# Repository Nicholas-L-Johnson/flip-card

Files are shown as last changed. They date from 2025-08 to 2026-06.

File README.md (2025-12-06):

This repo contains all files related to the flip-card project, which is a business card that runs a fluid-implicit-particle(FLIP) simulation.



The PCB design files are in the "kicad-pcb" folder. The flip-card project is inspired by mitxela's fluid simulation pendant project https://mitxela.com/projects/fluid-pendant

The fluid simulation logic is contained in a standalone crate, which is in the "fluid_sim_crate" folder. This is based off the work by Matthias Müller (https://github.com/matthias-research) and his excelent demonstrations on his youtube channel "Ten Minute Physics"

One of the more difficult features was the rechargable battery.  I found a design for a board edge usb-c port from cnlohr's tiny touch lcd project https://github.com/cnlohr/ch32v003_3digit_lcd_usb/



a WASM simulator is also provided in the "sim_display" folder, which is what I use to debug issues in the simulation.

The implementation for the fluid simulation on the rp2350 is in the "flip-card_firmware" file

further details can be found in each folder's README files, **see flashing instructions in the flip-card_firmware subfolder**



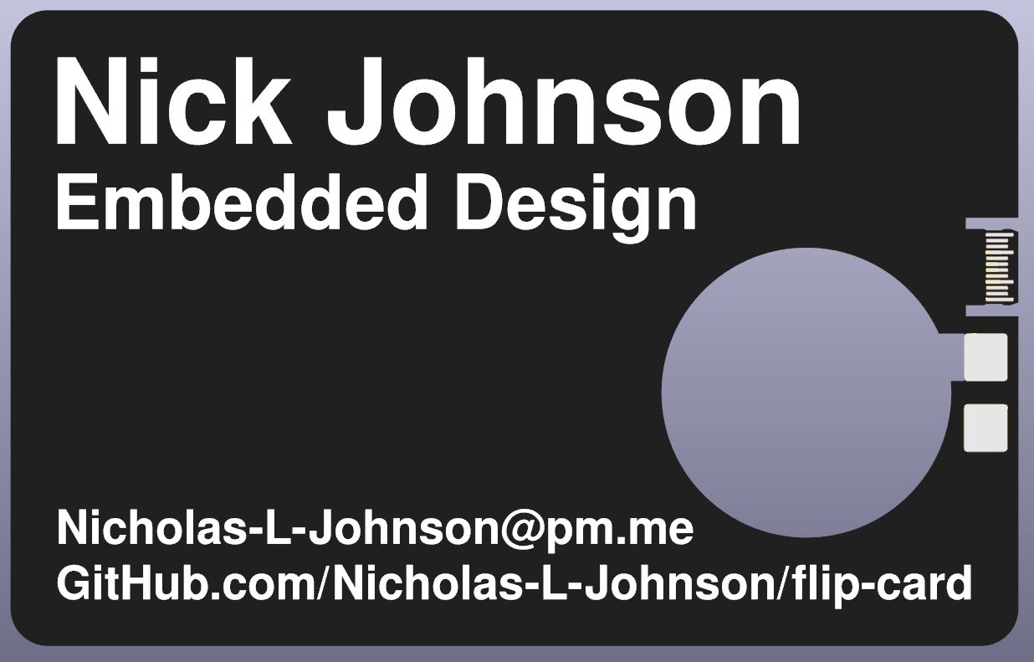
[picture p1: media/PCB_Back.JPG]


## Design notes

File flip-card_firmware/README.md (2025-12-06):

## Firmware
This is where all the logic lies for running the screen and reading the accelerometer.

Everything here centers around the Embassy framework.  Embassy is by far the easiest way to get into embedded rust.

Most of the complexity here stems from the need to drive a charlieplexed LED array.  The PIO peripheral is a godsend for this, it lets the data stream directly into GPIO signals without any use of the main 2 cores.

Speaking of performance, the simulation uses both cores running at 150 MHz.  The board runs at 40mA, and most of that is the controller, not the LEDs.  The lowest power mode available for the rust pac is the DORMANT state, which only brings the power usage down to 1.5mA.

That's really the only TODO here.  The RP2350 has some wonderful support for power domains, but the rust crates just don't support them yet.  Right now the card only lasts about 2-3 days in sleep mode before it needs charged again.

## Build and Install

Installing the firmware onto the card is pretty straightforward, just clone the whole repo into a folder and cd into the firmware folder.  There are two pre-requisites that must be met before flashing:

1) Because the card uses the Raspberry Pi Pico 2 (RP2350) you must have Picotool installed in order to load firmware.  You can find Picotool here: https://github.com/raspberrypi/picotool
2) The card must be connected via a usb-c cord (into the cutout on the board) and mount a volume when connected to your computer (it should do this by default for new cards, but read below for re-programming cards)

Once those pre-requisites are satisfied, you can install the firmware by simply running:
```
cargo run --release
```
(don't forget the --release or it will not work, and will need to be forced back to bootloader mode via the method below)

That will compile the binary, and then use picotool to load the binary onto the RP2350.

## Re-Programming an already programmed card

The card can be returned to bootloader mode (where it appears as a volume on a connected PC and can be re-flashed) in two ways.  

First, with the board powered, you can short the "GND" contact to the "BOOT" contact, then with that short in place, breifly short the "GND" contact to the "RUN" contact.  Then remove all the shorts and it should be in bootloader mode.

Second, the latest version of the code has a backup method. the card can be placed perfectly upside down (so all the fluid goes to the top of the screen) for 5 seconds, and that will kick it back to bootloader mode.  Note that the board will be stuck in that mode until the program is re-flashed, or the rp2350 loses all power.

## OPTIONAL

If you want to disable the backup method to go back to bootloader (becuse you don't want the card to ever accidentally go to bootloader mode) in main.rs, uncomment line 794 (the udf() function) and comment out line 793(the reboot() function), THEN run the build and install steps above.

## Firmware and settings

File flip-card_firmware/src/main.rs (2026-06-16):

#![no_std]
#![no_main]

use core::cell::RefCell;
use core::default;

use cortex_m::interrupt::{self, Mutex};
use embassy_executor::{Executor, Spawner};
use embassy_futures::select::{Either::First, select};
use embassy_rp::bind_interrupts;
use embassy_rp::gpio;
use embassy_rp::gpio::DormantWakeConfig;
use embassy_rp::gpio::Input;
use embassy_rp::gpio::Pull;
use heapless::Vec;
// use embassy_rp::gpio::{Input, Pull};
use embassy_rp::clocks::{ClockConfig, CoreVoltage, clk_sys_freq, core_voltage};
use embassy_rp::i2c;
use embassy_rp::i2c::I2c;
use embassy_rp::i2c::InterruptHandler as I2C_InterruptHandler;
use embassy_rp::multicore::{Stack, spawn_core1};
use embassy_rp::peripherals::*;
use embassy_rp::pio::program::pio_asm;
use embassy_rp::pio::{Config, InterruptHandler, Pio, ShiftConfig, ShiftDirection};
use embassy_rp::watchdog::*;
use embassy_sync::blocking_mutex::raw::CriticalSectionRawMutex;
use embassy_time::Duration;
use embassy_time::Timer;
use fixed::traits::ToFixed;
use fixed_macro::types::U56F8;
use fluid_sim::FluidSimulation::Scene;
use gpio::{Level, Output};

use static_cell::StaticCell;
// use {defmt_rtt as _, panic_probe as _};

static mut CORE1_STACK: Stack<262144> = Stack::new();
static EXECUTOR0: StaticCell<Executor> = StaticCell::new();
static EXECUTOR1: StaticCell<Executor> = StaticCell::new();
// static CHANNEL: Channel<CriticalSectionRawMutex, LedState, 1> = Channel::new();

static BIT21: u32 = 0b00000000001000000000000000000000; // pinout 19 1
static BIT20: u32 = 0b00000000000100000000000000000000; // pinout 19 2
static BIT19: u32 = 0b00000000000010000000000000000000; // pinout 19 3
static BIT18: u32 = 0b00000000000001000000000000000000; // pinout 18 4
static BIT17: u32 = 0b00000000000000100000000000000000; // pinout 17 5
static BIT16: u32 = 0b00000000000000010000000000000000; // pinout 16 6
static BIT15: u32 = 0b00000000000000001000000000000000; // pinout 15 7
static BIT14: u32 = 0b00000000000000000100000000000000; // pinout 14 8
static BIT13: u32 = 0b00000000000000000010000000000000; // pinout 13 9
static BIT12: u32 = 0b00000000000000000001000000000000; // pinout 12 10
static BIT11: u32 = 0b00000000000000000000100000000000; // pinout 11 11
static BIT10: u32 = 0b00000000000000000000010000000000; // pinout 10 12
static BIT9: u32 = 0b00000000000000000000001000000000; // pinout 9 13
static BIT8: u32 = 0b00000000000000000000000100000000; // pinout 8 14
static BIT7: u32 = 0b00000000000000000000000010000000; // pinout 7 15
static BIT6: u32 = 0b00000000000000000000000001000000; // pinout 6 16
static BIT5: u32 = 0b00000000000000000000000000100000; // pinout 5 17
static BIT4: u32 = 0b00000000000000000000000000010000; // pinout 4 18
static BIT3: u32 = 0b00000000000000000000000000001000; // pinout 3 19
static BIT2: u32 = 0b00000000000000000000000000000100; // pinout 2 20
static BIT1: u32 = 0b00000000000000000000000000000010; // pinout 1 21
static BIT0: u32 = 0b00000000000000000000000000000001; // pinout 1 21

static FRAME_DATA_SIGNAL: embassy_sync::signal::Signal<CriticalSectionRawMutex, [[bool; 21]; 21]> =
    embassy_sync::signal::Signal::new();

static ACCEL_DATA_SIGNAL: embassy_sync::signal::Signal<CriticalSectionRawMutex, [f32; 2]> =
    embassy_sync::signal::Signal::new();

static BITS: [u32; 22] = [
    BIT21, BIT20, BIT19, BIT18, BIT17, BIT16, BIT15, BIT14, BIT13, BIT12, BIT11, BIT10, BIT9, BIT8,
    BIT7, BIT6, BIT5, BIT4, BIT3, BIT2, BIT1, BIT0,
];
static WATCHDOG: Mutex<RefCell<Option<Watchdog>>> = Mutex::new(RefCell::new(None));

static LOOKUP_TABLE: [[usize; 21]; 21] = [
    [
        416, 481, 373, 435, 327, 389, 281, 343, 235, 297, 189, 251, 143, 205, 097, 159, 051, 113,
        005, 067, 025,
    ],
    [
        459, 372, 479, 329, 433, 283, 387, 237, 341, 191, 295, 145, 249, 099, 203, 053, 157, 007,
        111, 027, 068,
    ],
    [
        370, 457, 328, 477, 285, 431, 239, 385, 193, 339, 147, 293, 101, 247, 055, 201, 009, 155,
        029, 112, 071,
    ],
    [
        413, 326, 455, 284, 475, 241, 429, 195, 383, 149, 337, 103, 291, 057, 245, 011, 199, 031,
        156, 073, 114,
    ],
    [
        324, 411, 282, 453, 240, 473, 197, 427, 151, 381, 105, 335, 059, 289, 013, 243, 033, 200,
        075, 158, 117,
    ],
    [
        367, 280, 409, 238, 451, 196, 471, 153, 425, 107, 379, 061, 333, 015, 287, 035, 244, 077,
        202, 119, 160,
    ],
    [
        278, 365, 236, 407, 194, 449, 152, 469, 109, 423, 063, 377, 017, 331, 037, 288, 079, 246,
        121, 204, 163,
    ],
    [
        321, 234, 363, 192, 405, 150, 447, 108, 467, 065, 421, 019, 375, 039, 332, 081, 290, 123,
        248, 165, 206,
    ],
    [
        232, 319, 190, 361, 148, 403, 106, 445, 064, 465, 021, 419, 041, 376, 083, 334, 125, 292,
        167, 250, 209,
    ],
    [
        275, 188, 317, 146, 359, 104, 401, 062, 443, 020, 463, 043, 420, 085, 378, 127, 336, 169,
        294, 211, 252,
    ],
    [
        186, 273, 144, 315, 102, 357, 060, 399, 018, 441, 042, 464, 087, 422, 129, 380, 171, 338,
        213, 296, 255,
    ],
    [
        229, 142, 271, 100, 313, 058, 355, 016, 397, 040, 442, 086, 466, 131, 424, 173, 382, 215,
        340, 257, 298,
    ],
    [
        140, 227, 098, 269, 056, 311, 014, 353, 038, 398, 084, 444, 130, 468, 175, 426, 217, 384,
        259, 342, 301,
    ],
    [
        183, 096, 225, 054, 267, 012, 309, 036, 354, 082, 400, 128, 446, 174, 470, 219, 428, 261,
        386, 303, 344,
    ],
    [
        094, 181, 052, 223, 010, 265, 034, 310, 080, 356, 126, 402, 172, 448, 218, 472, 263, 430,
        305, 388, 347,
    ],
    [
        137, 050, 179, 008, 221, 032, 266, 078, 312, 124, 358, 170, 404, 216, 450, 262, 474, 307,
        432, 349, 390,
    ],
    [
        048, 135, 006, 177, 030, 222, 076, 268, 122, 314, 168, 360, 214, 406, 260, 452, 306, 476,
        351, 434, 393,
    ],
    [
        091, 004, 133, 028, 178, 074, 224, 120, 270, 166, 316, 212, 362, 258, 408, 304, 454, 350,
        478, 395, 436,
    ],
    [
        002, 089, 026, 134, 072, 180, 118, 226, 164, 272, 210, 318, 256, 364, 302, 410, 348, 456,
        394, 480, 439,
    ],
    [
        045, 024, 090, 070, 136, 116, 182, 162, 228, 208, 274, 254, 320, 300, 366, 346, 412, 392,
        458, 438, 482,
    ],
    [
        023, 046, 069, 092, 115, 138, 161, 184, 207, 230, 253, 276, 299, 322, 345, 368, 391, 414,
        437, 460, 461,
    ],
];

struct Screen {
    yx_grid: [[bool; 21]; 21],
    yx_lock_grid: [[bool; 21]; 21],
    index_grid: [bool; 484],
    out_array: [u32; 506],
    out_array_2: Vec<u32, 1452>,
}
impl Screen {
    fn fill_index(&mut self) {
        self.index_grid = [false; 484];
        for y in 0..21 {
            for x in 0..21 {
                if self.yx_grid[y][x] {
                    self.index_grid[LOOKUP_TABLE[y][x]] = true
                }
            }
        }
    }
    fn post_process(&mut self) {
        // Temporary grid to track which liquid cells will become stable/locked this frame
        let mut temp_yx_lock_grid = [[false; 21]; 21];

        // PHASE 1: Liquid Stabilization Detection
        // Find liquid cells that are completely contained (surrounded by liquid or boundaries)
        // These cells will become "stable" and won't flow away in future iterations
        for i in 0..21 {
            for j in 0..21 {
                if self.yx_grid[i][j] {
                    // Only process existing liquid cells
                    // Check if liquid is completely contained (can't flow in any direction)
                    // A cell is contained if all 4 neighbors are either liquid or boundaries
                    temp_yx_lock_grid[i][j] = (i == 20 || self.yx_grid[i + 1][j]) &&  // Bottom: boundary or liquid
                        (i == 0  || self.yx_grid[i - 1][j]) &&  // Top: boundary or liquid
                        (j == 20 || self.yx_grid[i][j + 1]) &&  // Right: boundary or liquid
                        (j == 0  || self.yx_grid[i][j - 1]); // Left: boundary or liquid
                }
            }
        }

        // PHASE 2: Stable Liquid Reinforcement
        // For liquid that was stable in the previous frame, check if it should remain liquid
        // This prevents stable liquid from disappearing due to flow dynamics
        for i in 0..21 {
            for j in 0..21 {
                if self.yx_lock_grid[i][j] {
                    // Process previously stable liquid
                    // Re-check if this stable liquid is still contained
                    let is_surrounded = (i == 20 || self.yx_grid[i + 1][j])
                        && (i == 0 || self.yx_grid[i - 1][j])
                        && (j == 20 || self.yx_grid[i][j + 1])
                        && (j == 0 || self.yx_grid[i][j - 1]);

                    if is_surrounded {
                        // Reinforce: ensure this cell remains liquid (prevent evaporation/flow)
                        self.yx_grid[i][j] = true;
                    }
                    // If not surrounded anymore, let natural flow dynamics handle it
                    // (don't force it to empty - preserve liquid conservation)
                }
            }
        }

        // Update stability tracking for next iteration
        // Replace old stable cell tracking with newly calculated stable cells
        self.yx_lock_grid = temp_yx_lock_grid;
    }
    fn make_output(&mut self) {
        self.out_array = [0; 506];
        let mut index = 0;
        let mut counter = 0;

        for i in 0..BITS.len() {
            self.out_array[counter] = BITS[i];
            index += 1;
            counter += 1;
            for j in 0..BITS.len() {
                if i != j {
                    if self.index_grid[index] {
                        self.out_array[counter] = BITS[i] | BITS[j];
                    }
                    index += 1;
                    counter += 1;
                }
            }
            // counter += 1;
        }
    }
    fn make_output_2(&mut self) {
        self.out_array_2 = Vec::new();
        let mut index = 0;
        for i in 0..BITS.len() {
            index += 1;
            for j in 0..BITS.len() {
                if i != j {
                    if self.index_grid[index] {
                        self.out_array_2.push(BITS[i]).unwrap();
                        self.out_array_2.push(BITS[i] | BITS[j]).unwrap();
                        self.out_array_2.push(0).unwrap();
                    }
                    index += 1;
                }
            }
        }
        if self.index_grid[461] {
            self.out_array_2.push(BITS[21]).unwrap();
            self.out_array_2.push(BITS[21] | BITS[20]).unwrap();
            self.out_array_2.push(0).unwrap();
        }
    }
    fn _disp_num(&mut self, num: usize, yloc: usize, xloc: usize) {
        let ymin = yloc;
        let ymax = yloc + 7;
        let xmin = xloc;
        let xmax = xloc + 5;

        for y in ymin..ymax {
            for x in xmin..xmax {
                self.yx_grid[y][x] = false;
            }
        }
        match num {
            0 => {
                self.yx_grid[ymin + 1][xmin + 1] = true;
                self.yx_grid[ymin + 2][xmin + 1] = true;
                self.yx_grid[ymin + 3][xmin + 1] = true;
                self.yx_grid[ymin + 4][xmin + 1] = true;
                self.yx_grid[ymin + 5][xmin + 1] = true;

                self.yx_grid[ymin + 1][xmin + 2] = true;
                //self.yx_grid[ymin +3][xmin + 2] = true;
                self.yx_grid[ymin + 5][xmin + 2] = true;

                self.yx_grid[ymin + 1][xmin + 3] = true;
                self.yx_grid[ymin + 2][xmin + 3] = true;
                self.yx_grid[ymin + 3][xmin + 3] = true;
                self.yx_grid[ymin + 4][xmin + 3] = true;
                self.yx_grid[ymin + 5][xmin + 3] = true;
            }
            1 => {
                // self.yx_grid[ymin + 1][xmin + 1] = true;
                // self.yx_grid[ymin + 2][xmin + 1] = true;
                // self.yx_grid[ymin + 3][xmin + 1] = true;
                // self.yx_grid[ymin + 4][xmin + 1] = true;
                // self.yx_grid[ymin + 5][xmin + 1] = true;

                // self.yx_grid[ymin + 1][xmin + 2] = true;
                // self.yx_grid[ymin +3][xmin + 2] = true;
                // self.yx_grid[ymin + 5][xmin + 2] = true;

                self.yx_grid[ymin + 1][xmin + 3] = true;
                self.yx_grid[ymin + 2][xmin + 3] = true;
                self.yx_grid[ymin + 3][xmin + 3] = true;
                self.yx_grid[ymin + 4][xmin + 3] = true;
                self.yx_grid[ymin + 5][xmin + 3] = true;
            }
            2 => {
                self.yx_grid[ymin + 1][xmin + 1] = true;
                // self.yx_grid[ymin + 2][xmin + 1] = true;
                self.yx_grid[ymin + 3][xmin + 1] = true;
                self.yx_grid[ymin + 4][xmin + 1] = true;
                self.yx_grid[ymin + 5][xmin + 1] = true;

                self.yx_grid[ymin + 1][xmin + 2] = true;
                self.yx_grid[ymin + 3][xmin + 2] = true;
                self.yx_grid[ymin + 5][xmin + 2] = true;
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
async fn main(_spawner: Spawner) {
    // define all the peripherals and pins
    // let mut config =
        // embassy_rp::config::Config::new(ClockConfig::system_freq(200_000_000).unwrap());
    // config.clocks.core_voltage = CoreVoltage::V1_15;
    let p = embassy_rp::init(Default::default());
    let mut i2c: I2c<'static, I2C1, i2c::Async> =
        embassy_rp::i2c::I2c::new_async(p.I2C1, p.PIN_23, p.PIN_22, Irqs, Default::default());
    interrupt::free(|cs| WATCHDOG.borrow(cs).replace(Some(Watchdog::new(p.WATCHDOG))));
    let mut enable_accel = Output::new(p.PIN_29, Level::Low);
    let pio: embassy_rp::Peri<'static, PIO0> = p.PIO0; //this PIO object is one of the 4 PIO peripherals
    let dma_out_ref: embassy_rp::Peri<'static, DMA_CH0> = p.DMA_CH0;
    let mut accel_interrupt_1 = Input::new(p.PIN_24, Pull::Up);
    let mut accel_interrupt_2 = Input::new(p.PIN_25, Pull::Up);
    // Timer::after_millis(10).await;

    // start up the peripherals
    let sm = setup_pio_2(
        pio, p.PIN_0, p.PIN_1, p.PIN_2, p.PIN_3, p.PIN_4, p.PIN_5, p.PIN_6, p.PIN_7, p.PIN_8,
        p.PIN_9, p.PIN_10, p.PIN_11, p.PIN_12, p.PIN_13, p.PIN_14, p.PIN_15, p.PIN_16, p.PIN_17,
        p.PIN_18, p.PIN_19, p.PIN_20, p.PIN_21,
    );
    enable_accel.set_high();
    let screen = Screen {
        yx_grid: [[false; 21]; 21],
        yx_lock_grid: [[false; 21]; 21],
        index_grid: [false; 484],
        out_array: [0; 506],
        out_array_2: Vec::new(),
    };

    // spawn background tasks

    spawn_core1(
        p.CORE1,
        unsafe { &mut *core::ptr::addr_of_mut!(CORE1_STACK) },
        move || {
            let executor1 = EXECUTOR1.init(Executor::new());
            executor1.run(|spawner| spawner.spawn(simulation_update()).unwrap())
        },
    );

    let executor0 = EXECUTOR0.init(Executor::new());
    executor0.run(|spawner| {
        spawner
            .spawn(monitor_accelerometer(
                i2c,
                accel_interrupt_1,
                accel_interrupt_2,
                enable_accel,
            ))
            .unwrap();
        spawner
            .spawn(drive_screen(screen, sm, dma_out_ref))
            .unwrap()
    });
}

#[embassy_executor::task(pool_size = 1)]
async fn drive_screen(
    mut screen: Screen,
    mut sm: embassy_rp::pio::StateMachine<'static, PIO0, 0>,
    mut dma_out_ref: embassy_rp::Peri<'static, DMA_CH0>,
) {
    let tx = sm.tx();
    let mut frame_count: u128 = 0;
    FRAME_DATA_SIGNAL.wait().await;
    loop {
        Timer::after_millis(1).await;
        interrupt::free(|cs| {
            if let Ok(mut watchdog) = WATCHDOG.borrow(cs).try_borrow_mut() {
                watchdog.as_mut().map(|w| w.feed());
            };
        });
        if FRAME_DATA_SIGNAL.signaled() {
            screen.yx_grid = FRAME_DATA_SIGNAL.wait().await;
            frame_count = 0;
            if screen.yx_grid == [[false; 21]; 21] {
                Timer::after_millis(3000).await;
            }
        } else {
            frame_count += 1;
        }
        screen.post_process();
        screen.fill_index();
        // screen.make_output();
        screen.make_output_2();
        tx.dma_push(dma_out_ref.reborrow(), &screen.out_array_2, false)
            .await;
        if frame_count >= 30 {
            // flash.blocking_write(reset_count_location, &[10u8]);
            // embassy_rp::rom_data::reboot(0x0002, 1, 0x00, 0x01); // reboot to BOOTSEL
            Timer::after_millis(3000).await;
        }
    }
}

#[embassy_executor::task(pool_size = 1)]
async fn monitor_accelerometer(
    mut i2c: I2c<'static, I2C1, i2c::Async>,
    mut int1: Input<'static>,
    mut int2: Input<'static>,
    mut enable_accel: Output<'static>,
) {
    //setup accelerometer
    let addr: u8 = 0x18;
    let dt: f32 = 1.0 / 100.0; // 1/Hz,
    let accel_scale_max: f32 = 9.81 * 8.0; // m/s²
    let mut xh: [u8; 1] = [0];
    i2c.blocking_write(addr, &[0x24, 0x08]).unwrap(); // CTRL_REG5, reboot chip
    i2c.blocking_write(addr, &[0x24, 0x80]).unwrap(); // CTRL_REG1, turn on, enable xyz
    Timer::after_millis(100).await;
    i2c.blocking_write(addr, &[0x20, 0x77]).unwrap(); // CTRL_REG1, turn on, enable xyz
    i2c.blocking_write(addr, &[0x21, 0x00]).unwrap(); // CTRL_REG2, high pass filter off
    i2c.blocking_write(addr, &[0x22, 0x80]).unwrap(); // CTRL_REG3, click to INT1 pin
    i2c.blocking_write(addr, &[0x23, 0x20]).unwrap(); // CTRL_REG4, FS = 8G
    // i2c.blocking_write(addr, &[0x24, 0x08]).unwrap(); // CTRL_REG5, latch INT pin 1
    i2c.blocking_write(addr, &[0x32, 0x0A]).unwrap(); // INT1_THS, Threshold = 250 mg
    i2c.blocking_write(addr, &[0x33, 0x7F]).unwrap(); // INT1_DURATION, Duration = 0
    i2c.blocking_write(addr, &[0x38, 0x22]).unwrap(); // CLICK_CFG
    i2c.blocking_write(addr, &[0x39, 0x27]).unwrap(); // CLICK_SRC
    i2c.blocking_write(addr, &[0x3A, 0x40]).unwrap(); // CLICK_THS
    i2c.blocking_write(addr, &[0x3B, 0x20]).unwrap(); // TIME_LIMIT
    i2c.blocking_write(addr, &[0x3C, 0x2F]).unwrap(); // TIME_LATENCY
    i2c.blocking_write(addr, &[0x3D, 0x30]).unwrap(); // TIME WINDOW
    // i2c.blocking_write(addr, &[0x30, 0x02]).unwrap(); // INT1_CFG, enable xh and yh interrupts
    // int1.wait_for_high().await;
    enable_accel.set_low();
    let dormant_config = DormantWakeConfig {
        edge_high: false,
        edge_low: false,
        level_high: true,
        level_low: false,
    };
    let wake = int1.dormant_wake(dormant_config.clone());
    let wake2 = int2.dormant_wake(dormant_config.clone());
    embassy_rp::clocks::dormant_sleep();
    interrupt::free(|cs| {
        if let Ok(mut watchdog) = WATCHDOG.borrow(cs).try_borrow_mut() {
            watchdog
                .as_mut()
                .map(|w| w.start(Duration::from_millis(500)));
            //.start(Duration::from_millis(500));
        };
    });
    drop(wake);
    drop(wake2);

    enable_accel.set_high();
    // i2c.blocking_write(addr, &[0x24, 0x80]).unwrap(); // CTRL_REG5, reboot chip
    i2c.blocking_write(addr, &[0x20, 0x57]).unwrap(); // CTRL_REG1, turn on, enable xy
    i2c.blocking_write(addr, &[0x23, 0x20]).unwrap(); // CTRL_REG1, turn on, enable xy
    //read accelerometer
    let mut yh: [u8; 1] = [0];
    let mut x_val: i8;
    let mut y_val: i8;
    let mut normalized_x_accel: f32;
    let mut normalized_y_accel: f32;
    let mut y_counter: usize = 0;
    let mut frame_count = 0;
    loop {
        Timer::after_millis(5).await;
        // if frame_count > 14 {
        //     embassy_rp::rom_data::reboot(0x0002, 1, 0x00, 0x01); // reboot to BOOTSEL
        // } else {
        //     frame_count += 1;
        // }
        i2c.write_read_async(addr, [0x29], &mut xh).await.unwrap(); // read accel data
        i2c.write_read_async(addr, [0x2B], &mut yh).await.unwrap(); // read accel data
        x_val = xh[0] as i8;
        y_val = yh[0] as i8;
        normalized_x_accel = (15.0 * accel_scale_max * (x_val as f32) / 128.0);
        normalized_y_accel = (15.0 * accel_scale_max * (y_val as f32) / 128.0);

        if y_val > 10 {
            y_counter += 1;
            if y_counter > 1000 {
                //embassy_rp::rom_data::reboot(0x0002, 1, 0x00, 0x01); // reboot to BOOTSEL
                cortex_m::asm::udf();
            }
        } else {
            if y_counter > 0 {
                y_counter -= 1;
            }
        }

        ACCEL_DATA_SIGNAL.signal([normalized_x_accel, -normalized_y_accel]);
    }
}

#[embassy_executor::task]
async fn simulation_update() {
    let mut scene = Scene::setupScene(250);
    ACCEL_DATA_SIGNAL.wait().await;
    let mut frame_count = 0;
    let mut miss_count = 0;
    let mut shake_count = 0;
    loop {
        if let First(accel_measurment) =
            select(ACCEL_DATA_SIGNAL.wait(), Timer::after_millis(10)).await
        {
            miss_count = 0;
            scene.set_gravity(accel_measurment);
            if accel_measurment[1] > 211.0 || accel_measurment[1] < -211.0 {
                shake_count += 100;
                if shake_count > 400 {
                    scene.particle_add(250, 250);
                }
            } else if shake_count > 0 {
                shake_count -= 1;
            }
        } else {
            miss_count += 1
        }
        if frame_count > 1000 {
            if frame_count % 60 == 0 {
                scene.particle_add(-1, 250);
            }
        }

        if !scene.is_paused() && scene.get_num_particles() > 0 && miss_count < 10 {
            frame_count += 1;
            scene.simulate();
            FRAME_DATA_SIGNAL.signal(scene.get_output());
        } else {
            if miss_count > 9 {
                cortex_m::asm::udf();
            }
            // ACCEL_DATA_SIGNAL.wait().await;
        }
    }
}
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

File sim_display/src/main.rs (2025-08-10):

use std::cell::RefCell;
use std::f32::consts::PI;
use std::rc::Rc;


use fluid_sim::FluidSimulation::*;
use wasm_bindgen::JsCast;
use wasm_bindgen::prelude::*;
use web_sys::{KeyboardEvent,HtmlCanvasElement, WebGlRenderingContext as GL, WebGlRenderingContext, window};
use yew::{Component, Context, Html, NodeRef, html};



// Wrap gl in Rc (Arc for multi-threaded) so it can be injected into the render-loop closure.
pub struct App {
    node_ref: NodeRef,
}

impl Component for App {
    type Message = ();
    type Properties = ();

    fn create(_ctx: &Context<Self>) -> Self {
        Self {
            node_ref: NodeRef::default(),
        }
    }

    fn view(&self, ctx: &Context<Self>) -> Html {

        let on_key_press = ctx.link().callback(|event: KeyboardEvent| {
            if event.key() == "Enter" {
                // Handle Enter key press
            } else {
                // Handle other key presses
            }
        });
        html! {
            <canvas width="600" height="600" tabindex="0" ref={self.node_ref.clone()} />
        }
    }

    fn rendered(&mut self, _ctx: &Context<Self>, first_render: bool) {
        // Only start the render loop if it's the first render
        // There's no loop cancellation taking place, so if multiple renders happen,
        // there would be multiple loops running. That doesn't *really* matter here because
        // there's no props update and no SSR is taking place, but it is something to keep in
        // consideration
        if !first_render {
            return;
        }
        // Once rendered, store references for the canvas and GL context. These can be used for
        // resizing the rendering area when the window or canvas element are resized, as well as
        // for making GL calls.
        let canvas = self.node_ref.cast::<HtmlCanvasElement>().unwrap();
        canvas.focus().unwrap();
        let gl: GL = canvas
            .get_context("webgl")
            .unwrap()
            .unwrap()
            .dyn_into()
            .unwrap();
        Self::render_gl(gl);
    }
}

impl App {
    fn request_animation_frame(f: &Closure<dyn FnMut()>) {
        window()
            .unwrap()
            .request_animation_frame(f.as_ref().unchecked_ref())
            .expect("should register `requestAnimationFrame` OK");
    }

    fn render_gl(gl: WebGlRenderingContext) {
        let mut scene = Scene::setupScene(400);
        let gravity = Rc::new(RefCell::new([-10.0,-10.0]));
        {
            let gravity = gravity.clone();
            let keydown_closure = Closure::wrap(Box::new(move |event: KeyboardEvent| {
                event.prevent_default();
                let mut g = gravity.borrow_mut();
                match event.key().as_str() {
                    "ArrowUp" => {
                        web_sys::console::log_1(&"Keyup".into());
                        g[0] = 200.0;
                        g[1] = 0.0;
                    }
                    "ArrowDown" => {
                        g[0] = -200.0;
                        g[1] = 0.0;
                    }
                    "ArrowLeft" => {
                        g[0] = 0.0;
                        g[1] = -200.0;
                    }
                    "ArrowRight" => {
                        g[0] = 0.0;
                        g[1] = 200.0;
                    }
                    _ => {}
                }
            }) as Box<dyn FnMut(_)>);

        
            window()
                .unwrap()
                .add_event_listener_with_callback("keydown", keydown_closure.as_ref().unchecked_ref())
                .unwrap();
        web_sys::console::log_1(&"Keydown listener added".into());
            keydown_closure.forget(); // Don't drop the closure
        }
        
        // This should log only once -- not once per frame

        let mut timestamp = 0.0;

        let vert_code = include_str!("./basic.vert");
        let frag_code = include_str!("./basic.frag");

        // This list of vertices will draw two triangles to cover the entire canvas.
        let vertices: Vec<f32> = Vec::new();
        let vertex_buffer = gl.create_buffer().unwrap();
        let verts = js_sys::Float32Array::from(vertices.as_slice());

        gl.bind_buffer(GL::ARRAY_BUFFER, Some(&vertex_buffer));
        gl.buffer_data_with_array_buffer_view(GL::ARRAY_BUFFER, &verts, GL::STATIC_DRAW);

        let vert_shader = gl.create_shader(GL::VERTEX_SHADER).unwrap();
        gl.shader_source(&vert_shader, vert_code);
        gl.compile_shader(&vert_shader);

        let frag_shader = gl.create_shader(GL::FRAGMENT_SHADER).unwrap();
        gl.shader_source(&frag_shader, frag_code);
        gl.compile_shader(&frag_shader);

        let shader_program = gl.create_program().unwrap();
        gl.attach_shader(&shader_program, &vert_shader);
        gl.attach_shader(&shader_program, &frag_shader);
        gl.link_program(&shader_program);

        gl.use_program(Some(&shader_program));

        // Attach the position vector as an attribute for the GL context.
        let position = gl.get_attrib_location(&shader_program, "a_position") as u32;
        gl.vertex_attrib_pointer_with_i32(position, 2, GL::FLOAT, false, 0, 0);
        gl.enable_vertex_attrib_array(position);

        // Attach the time as a uniform for the GL context.
        let time = gl.get_uniform_location(&shader_program, "u_time");
        gl.uniform1f(time.as_ref(), timestamp as f32);

        gl.draw_arrays(GL::TRIANGLES, 0, 6);

        // Gloo-render's request_animation_frame has this extra closure
        // wrapping logic running every frame, unnecessary cost.
        // Here constructing the wrapped closure just once.

        let cb = Rc::new(RefCell::new(None));
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

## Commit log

2025-08-10 fixed the WASM visualizer
    [main.rs]
2025-08-12 Changed to panic abort
    [RP2350_60QFN_minimal-B_Cu.gbr, RP2350_60QFN_minimal-B_Mask.gbr, RP2350_60QFN_minimal-B_Paste.gbr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]
2025-08-12 Fixed some crashes, updated PCB text
    [RP2350_60QFN_minimal-B_Cu.gbr, RP2350_60QFN_minimal-B_Mask.gbr, RP2350_60QFN_minimal-B_Paste.gbr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]
2025-08-12 fix post process: the 2nd matrix iteration was not changing the value on false
    [main.rs]
2025-09-11 hopefully fixed the crashing issue on the card
    [main.rs]
2026-06-16 fixed incompressibility, tunded sim
    [main.rs]
